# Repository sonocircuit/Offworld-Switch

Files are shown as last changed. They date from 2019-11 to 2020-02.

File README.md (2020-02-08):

# OFFWORLD/SWITCH

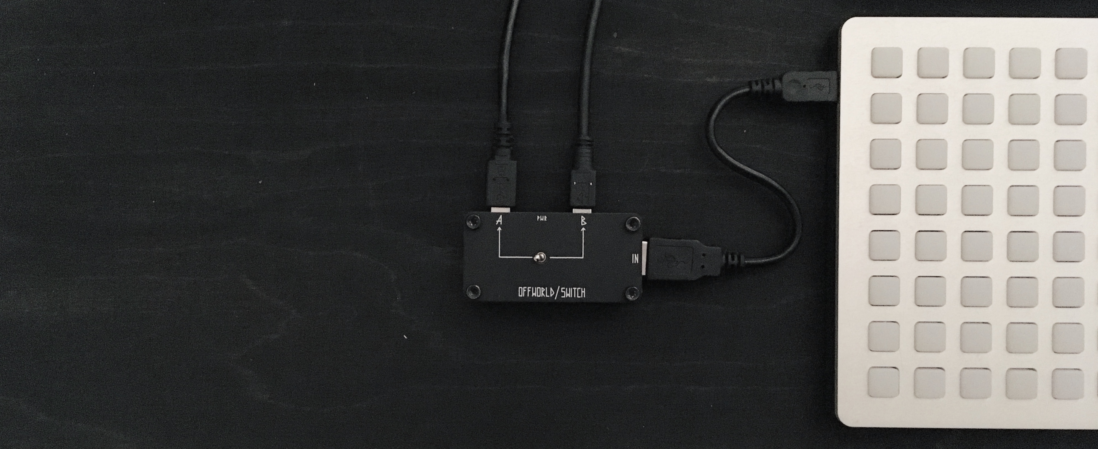
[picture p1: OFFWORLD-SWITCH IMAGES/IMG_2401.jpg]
DEVICE


The OFFWORLD/SWITCH is a small device to switch the USB data lines of a device between two hosts (A and B).

I needed a small device to switch the usb connection between a Norns and Ansible. While designing I deceded to incorporate monome's idea of the [offworld-1 device](https://github.com/monome/offworld-1). A more appropriate name would be "WORLD/SELECTOR" as it only works as offworld when the jumper is in the center position.

## How to use
There are three miniUSB B connectors on the rear and one USB A connector on the side. The Datalines D+/D- of the USB A are switched between the two outer miniUSB B connectors (A and B) via switch. <br>
The center miniUSB B connector provides +5V only.

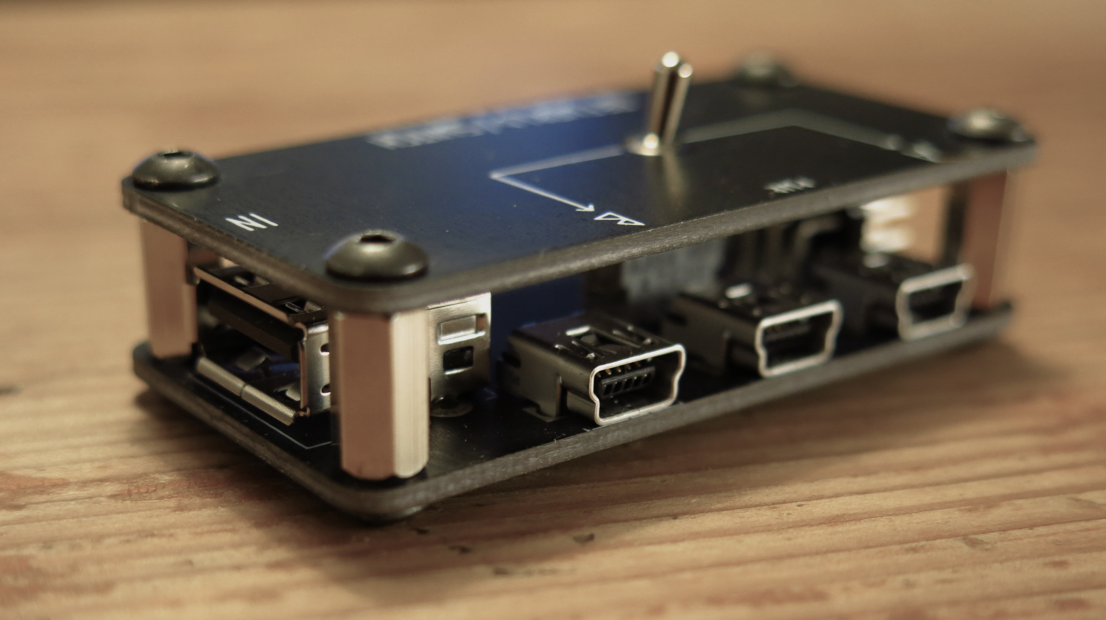
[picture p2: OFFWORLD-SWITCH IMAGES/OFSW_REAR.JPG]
Side Image


The miniUSB connector powering the device connected to the USB A can be selected via jumper. <br>
Top position A, middle position PWR and bottom position B.

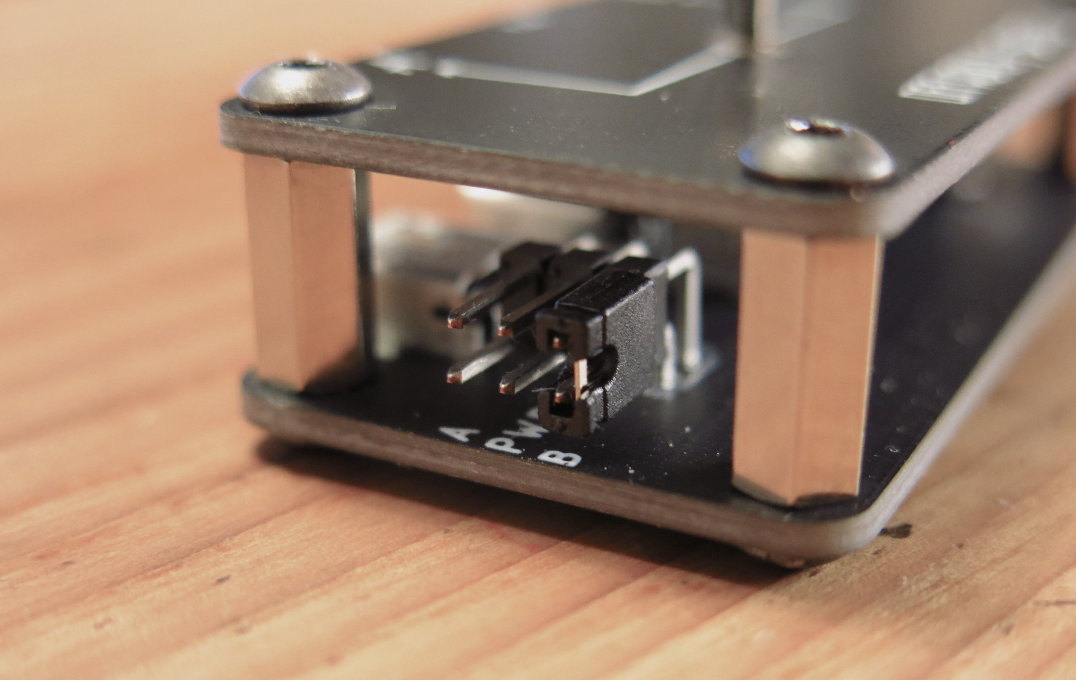
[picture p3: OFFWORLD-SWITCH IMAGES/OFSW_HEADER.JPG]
Header Image


## Future improvements

* replace the 6pin jumper with a three way switch. However, while testing, hotswiching the power source made Norns crash on several occations.

## Make your own

[Eagle files](https://github.com/sonoCircuits/Offworld-Switch/tree/master/OFFWORLD-SWITCH%20EAGLE%20FILES)

[Octopart BOM](https://octopart.com/bom-tool/UnnvVqt7)

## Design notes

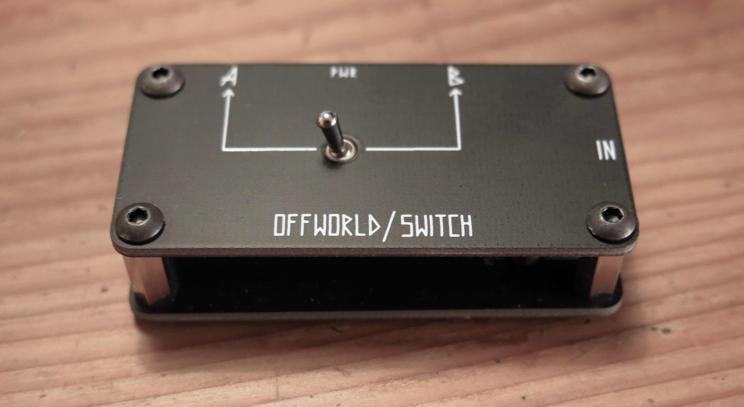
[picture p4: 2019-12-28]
OFFWORLD-SWITCH IMAGES/OFSW_TOP.JPG

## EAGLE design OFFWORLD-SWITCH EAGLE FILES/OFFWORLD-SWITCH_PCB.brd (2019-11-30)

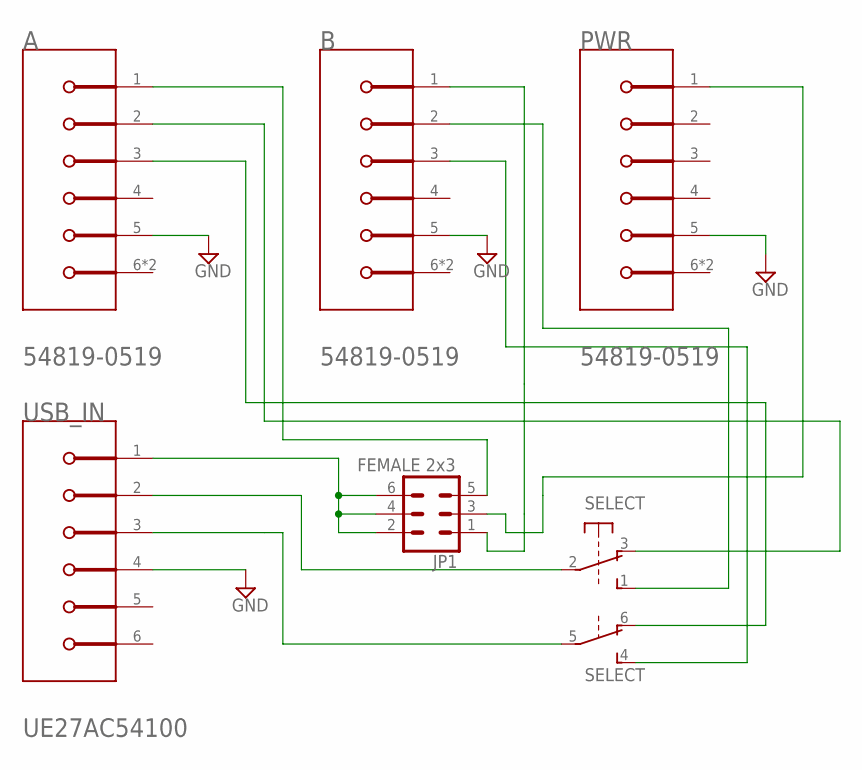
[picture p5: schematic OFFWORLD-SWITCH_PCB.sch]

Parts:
A: MOLEX_54819-0519MOLEX_54819-0519_0_0; MOLEX_54819-0519_0
B: MOLEX_54819-0519MOLEX_54819-0519_0_0; MOLEX_54819-0519_0
JP1: FEMALE 2x3; 2X3
PWR: MOLEX_54819-0519MOLEX_54819-0519_0_0; MOLEX_54819-0519_0
SELECT: 9450-2
USB_IN: AMPHENOL_UE27AC54100AMPHENOL_UE27AC54100_0_0; AMPHENOL_UE27AC54100_0

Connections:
GND: A.5 (GND), B.5 (GND), PWR.5 (GND), USB_IN.4
unnamed: JP1.2, JP1.4, JP1.6, USB_IN.1
unnamed: SELECT.2, USB_IN.2
unnamed: SELECT.5, USB_IN.3
unnamed: A.1 (VBUS), JP1.5
unnamed: JP1.3, PWR.1 (VBUS)
unnamed: B.1 (VBUS), JP1.1
unnamed: B.2 (D-), SELECT.1 (S)
unnamed: B.3 (D+), SELECT.4 (S)
unnamed: A.2 (D-), SELECT.3 (O)
unnamed: A.3 (D+), SELECT.6 (O)

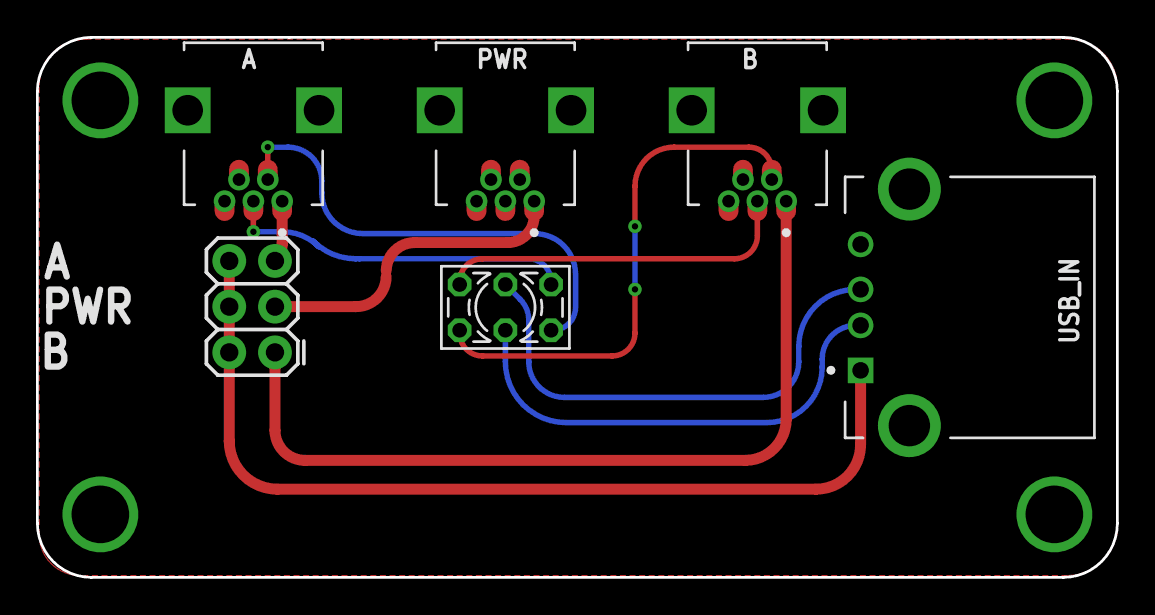
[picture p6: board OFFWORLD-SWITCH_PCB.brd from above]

Board: 2 copper layers, 60.0 x 30.0 mm, 6 parts (0 on the bottom side), 11 nets.

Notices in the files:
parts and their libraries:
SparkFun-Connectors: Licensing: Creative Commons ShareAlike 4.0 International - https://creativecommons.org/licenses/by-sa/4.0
